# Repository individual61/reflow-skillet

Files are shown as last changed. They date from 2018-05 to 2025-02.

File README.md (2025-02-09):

# reflow-skillet

A reflow oven based on a cheap Target skillet, with OLED display screen and thermocouple input. Now on a custom PCB.

IMG_8690_result

IMG_4667_result

IMG_4640_result

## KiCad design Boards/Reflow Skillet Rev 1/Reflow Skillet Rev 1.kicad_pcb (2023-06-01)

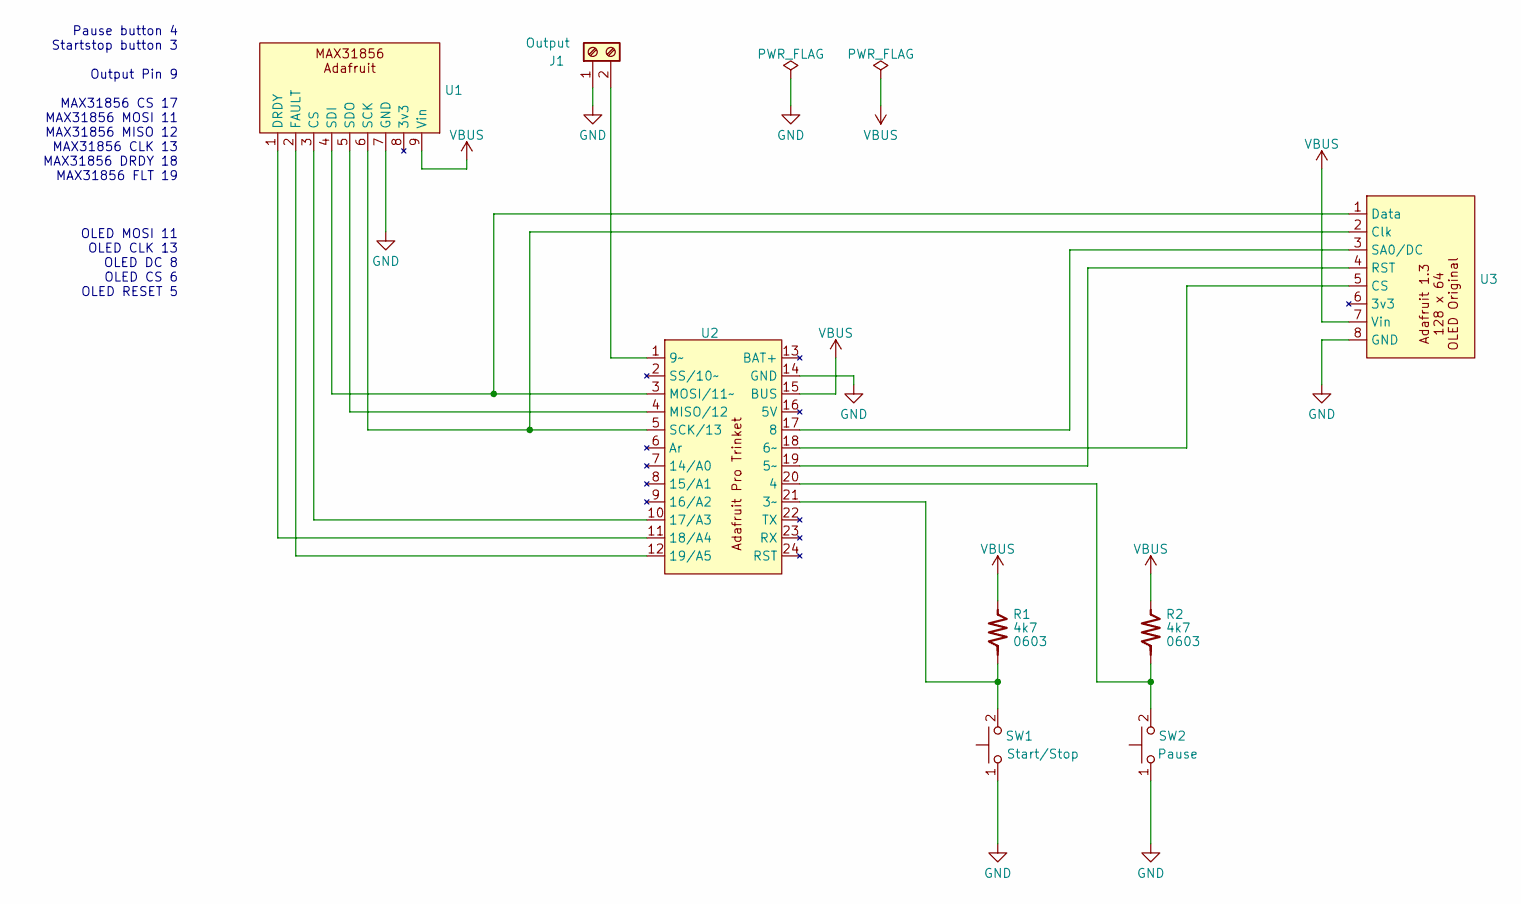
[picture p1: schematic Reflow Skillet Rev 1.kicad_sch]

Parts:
J1: Output; TerminalBlock_TE_282834-2_1x02_P2.54mm_Horizontal; MFR PN 282834-2; DIGIKEY PN A98333-ND
R1, R2: 4k7; R_0603_1608Metric_Pad0.98x0.95mm_HandSolder; MPN MFR P/N
SW1: Start/Stop; SW_TH_Tactile_Omron_B3F-10xx
SW2: Pause; SW_TH_Tactile_Omron_B3F-10xx
U1: Adafruit MAX31856
U2: Adafruit Pro Trinket
U3: Adafruit 1.3 128 x 64 OLED Original

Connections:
GND: J1.1, SW1.1, SW2.1, U1.7 (GND), U2.14 (GND), U3.8 (GND)
unnamed: J1.2, U2.1 (9~)
unnamed: U1.3 (CS), U2.10 (17/A3)
unnamed: U1.1 (DRDY), U2.11 (18/A4)
unnamed: U1.2 (FAULT), U2.12 (19/A5)
unnamed: U1.6 (SCK), U2.5 (SCK/13), U3.2 (Clk)
unnamed: U1.4 (SDI), U2.3 (MOSI/11~), U3.1 (Data)
unnamed: U1.5 (SDO), U2.4 (MISO/12)
unnamed: R1.2, SW1.2, U2.21 (3~)
unnamed: R2.2, SW2.2, U2.20 (4)
unnamed: U2.19 (5~), U3.4 (RST)
unnamed: U2.18 (6~), U3.5 (CS)
unnamed: U2.17 (8), U3.3 (SA0/DC)
VBUS: R1.1, R2.1, U1.9 (Vin), U2.15 (BUS), U3.7 (Vin)

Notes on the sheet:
Pause button 4 Startstop button 3 Output Pin 9 MAX31856 CS 17 MAX31856 MOSI 11 MAX31856 MISO 12 MAX31856 CLK 13 MAX31856 DRDY 18 MAX31856 FLT 19 OLED MOSI 11 OLED CLK 13 OLED DC 8 OLED CS 6 OLED RESET 5

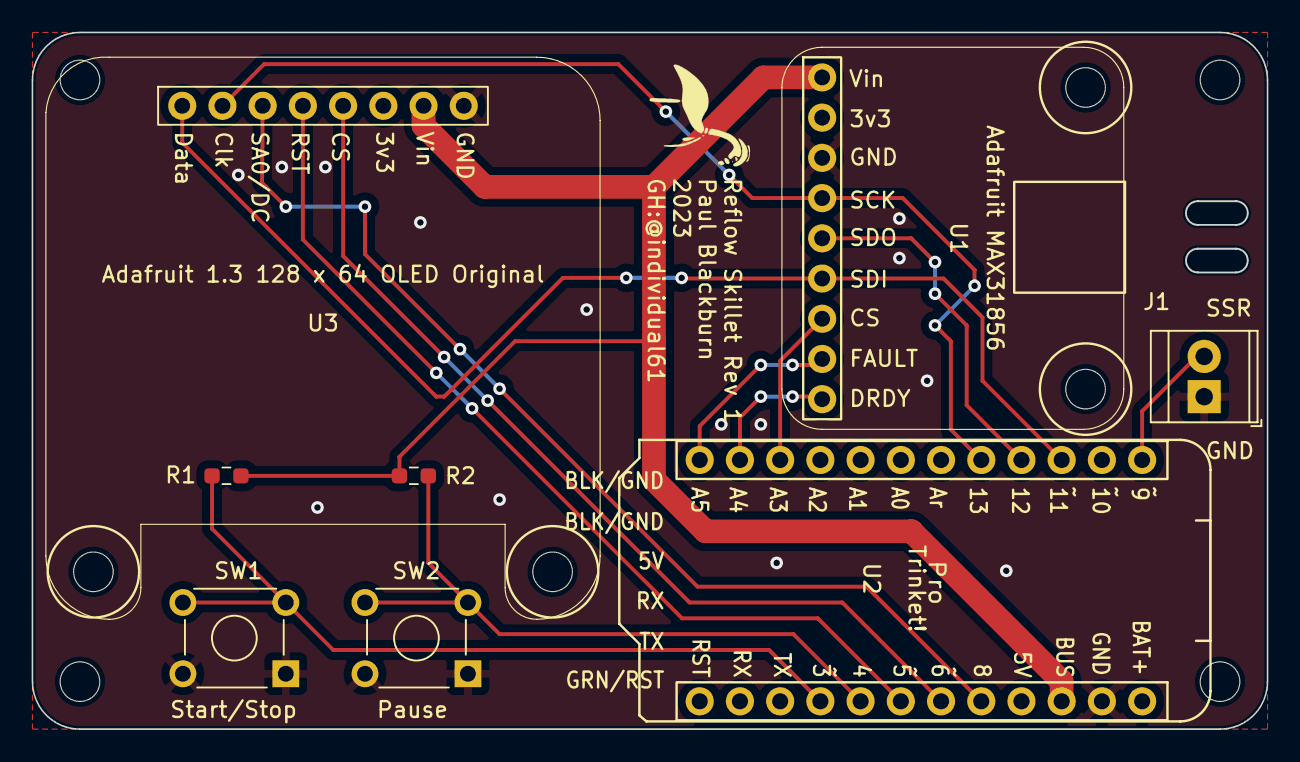
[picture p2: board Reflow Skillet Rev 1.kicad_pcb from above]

Board: 2 copper layers, 78.0 x 44.0 mm, 8 parts (0 on the bottom side), 14 nets.

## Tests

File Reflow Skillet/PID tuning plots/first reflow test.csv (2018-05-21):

Setpoint | Actual | Output
0 | 0 | 0
0 | 0 | 0
0 | 0 | 0
0 | 0 | 0
0 | 0 | 0
0 | 0 | 0
0 | 0 | 0
0 | 0 | 0
0 | 0 | 0
0 | 0 | 0
0 | 0 | 0
0 | 0 | 0
0 | 0 | 0
0 | 0 | 0
0 | 0 | 0
0 | 0 | 0
0 | 0 | 0
0 | 0 | 0
0 | 0 | 0
0 | 0 | 0
0 | 0 | 0
0 | 0 | 0
0 | 0 | 0
0 | 0 | 0
0 | 0 | 0
0 | 0 | 0
0 | 0 | 0
0 | 0 | 0
0 | 0 | 0
0 | 0 | 0
0 | 0 | 0
0 | 0 | 0
0 | 0 | 0
0 | 0 | 0
0 | 0 | 0
0 | 0 | 0
0 | 0 | 0
0 | 0 | 0
0 | 0 | 0
0 | 0 | 0
0 | 0 | 0
0 | 0 | 0
0 | 0 | 0
0 | 0 | 0
0 | 0 | 0
0 | 0 | 0
0 | 0 | 0
0 | 0 | 0
0 | 0 | 0
0 | 0 | 0
0 | 0 | 0
0 | 0 | 0
0 | 0 | 0
0 | 0 | 0
0 | 0 | 0
0 | 0 | 0
0 | 0 | 0
0 | 0 | 0
0 | 0 | 0
0 | 0 | 0
0 | 0 | 0
0 | 0 | 0
0 | 0 | 0
0 | 0 | 0
0 | 0 | 0
0 | 0 | 0
0 | 0 | 0
0 | 0 | 0
0 | 0 | 0
0 | 0 | 0
0 | 0 | 0
0 | 0 | 0
0 | 0 | 0
0 | 0 | 0
0 | 0 | 0
0 | 0 | 0
0 | 0 | 0
0 | 0 | 0
0 | 0 | 0
0 | 0 | 0
0 | 0 | 0
0 | 0 | 0
0 | 0 | 0
0 | 0 | 0
0 | 0 | 0
0 | 0 | 0
0 | 0 | 0
0 | 0 | 0
0 | 0 | 0
0 | 0 | 0
0 | 0 | 0
0 | 0 | 0
0 | 0 | 0
0 | 0 | 0
0 | 0 | 0
0 | 0 | 0
0 | 0 | 0
0 | 0 | 0
0 | 0 | 0
0 | 0 | 0
0 | 0 | 0
0 | 0 | 0
0 | 0 | 0
0 | 0 | 0
0 | 0 | 0
0 | 0 | 0
0 | 0 | 0
0 | 0 | 0
0 | 0 | 0
0 | 0 | 0
0 | 0 | 0
0 | 0 | 0
0 | 0 | 0
0 | 0 | 0
0 | 0 | 0
0 | 0 | 0
0 | 0 | 0
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

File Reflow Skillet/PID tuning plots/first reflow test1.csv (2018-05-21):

Setpoint | Actual | Output
0 | 0 | 0
0 | 0 | 0
0 | 0 | 0
0 | 0 | 0
0 | 0 | 0
0 | 0 | 0
0 | 0 | 0
0 | 0 | 0
0 | 0 | 0
0 | 0 | 0
0 | 0 | 0
0 | 0 | 0
0 | 0 | 0
0 | 0 | 0
0 | 0 | 0
0 | 0 | 0
0 | 0 | 0
0 | 0 | 0
0 | 0 | 0
0 | 0 | 0
0 | 0 | 0
0 | 0 | 0
0 | 0 | 0
0 | 0 | 0
0 | 0 | 0
0 | 0 | 0
0 | 0 | 0
0 | 0 | 0
0 | 0 | 0
0 | 0 | 0
0 | 0 | 0
0 | 0 | 0
0 | 0 | 0
0 | 0 | 0
0 | 0 | 0
0 | 0 | 0
0 | 0 | 0
0 | 0 | 0
0 | 0 | 0
0 | 0 | 0
0 | 0 | 0
0 | 0 | 0
0 | 0 | 0
0 | 0 | 0
0 | 0 | 0
0 | 0 | 0
0 | 0 | 0
0 | 0 | 0
0 | 0 | 0
0 | 0 | 0
0 | 0 | 0
0 | 0 | 0
0 | 0 | 0
0 | 0 | 0
0 | 0 | 0
0 | 0 | 0
0 | 0 | 0
0 | 0 | 0
0 | 0 | 0
0 | 0 | 0
0 | 0 | 0
0 | 0 | 0
0 | 0 | 0
0 | 0 | 0
0 | 0 | 0
0 | 0 | 0
0 | 0 | 0
0 | 0 | 0
0 | 0 | 0
0 | 0 | 0
0 | 0 | 0
0 | 0 | 0
0 | 0 | 0
0 | 0 | 0
0 | 0 | 0
0 | 0 | 0
0 | 0 | 0
0 | 0 | 0
0 | 0 | 0
0 | 0 | 0
0 | 0 | 0
0 | 0 | 0
0 | 0 | 0
0 | 0 | 0
0 | 0 | 0
0 | 0 | 0
0 | 0 | 0
0 | 0 | 0
0 | 0 | 0
0 | 0 | 0
0 | 0 | 0
0 | 0 | 0
0 | 0 | 0
0 | 0 | 0
0 | 0 | 0
0 | 0 | 0
0 | 0 | 0
0 | 0 | 0
0 | 0 | 0
0 | 0 | 0
0 | 0 | 0
0 | 0 | 0
0 | 0 | 0
0 | 0 | 0
0 | 0 | 0
0 | 0 | 0
0 | 0 | 0
0 | 0 | 0
0 | 0 | 0
0 | 0 | 0
0 | 0 | 0
0 | 0 | 0
0 | 0 | 0
0 | 0 | 0
0 | 0 | 0
0 | 0 | 0
0 | 0 | 0
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

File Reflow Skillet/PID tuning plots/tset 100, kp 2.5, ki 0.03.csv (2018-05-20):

Setpoint | Actual | Output
0 | 0 | 0
0 | 0 | 0
0 | 0 | 0
0 | 0 | 0
0 | 0 | 0
0 | 0 | 0
0 | 0 | 0
0 | 0 | 0
0 | 0 | 0
0 | 0 | 0
0 | 0 | 0
0 | 0 | 0
0 | 0 | 0
0 | 0 | 0
0 | 0 | 0
0 | 0 | 0
0 | 0 | 0
0 | 0 | 0
0 | 0 | 0
0 | 0 | 0
0 | 0 | 0
0 | 0 | 0
0 | 0 | 0
0 | 0 | 0
0 | 0 | 0
0 | 0 | 0
0 | 0 | 0
0 | 0 | 0
0 | 0 | 0
0 | 0 | 0
0 | 0 | 0
0 | 0 | 0
0 | 0 | 0
0 | 0 | 0
0 | 0 | 0
0 | 0 | 0
0 | 0 | 0
0 | 0 | 0
0 | 0 | 0
0 | 0 | 0
0 | 0 | 0
0 | 0 | 0
0 | 0 | 0
0 | 0 | 0
0 | 0 | 0
0 | 0 | 0
0 | 0 | 0
0 | 0 | 0
0 | 0 | 0
0 | 0 | 0
0 | 0 | 0
0 | 0 | 0
0 | 0 | 0
0 | 0 | 0
0 | 0 | 0
0 | 0 | 0
0 | 0 | 0
0 | 0 | 0
0 | 0 | 0
0 | 0 | 0
0 | 0 | 0
0 | 0 | 0
0 | 0 | 0
0 | 0 | 0
0 | 0 | 0
0 | 0 | 0
0 | 0 | 0
0 | 0 | 0
0 | 0 | 0
0 | 0 | 0
0 | 0 | 0
0 | 0 | 0
0 | 0 | 0
0 | 0 | 0
0 | 0 | 0
0 | 0 | 0
0 | 0 | 0
0 | 0 | 0
0 | 0 | 0
0 | 0 | 0
0 | 0 | 0
0 | 0 | 0
0 | 0 | 0
0 | 0 | 0
0 | 0 | 0
0 | 0 | 0
0 | 0 | 0
0 | 0 | 0
0 | 0 | 0
0 | 0 | 0
0 | 0 | 0
0 | 0 | 0
0 | 0 | 0
0 | 0 | 0
0 | 0 | 0
0 | 0 | 0
0 | 0 | 0
0 | 0 | 0
0 | 0 | 0
0 | 0 | 0
0 | 0 | 0
0 | 0 | 0
0 | 0 | 0
0 | 0 | 0
0 | 0 | 0
0 | 0 | 0
0 | 0 | 0
0 | 0 | 0
0 | 0 | 0
0 | 0 | 0
0 | 0 | 0
0 | 0 | 0
0 | 0 | 0
0 | 0 | 0
0 | 0 | 0
0 | 0 | 0
0 | 0 | 0
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

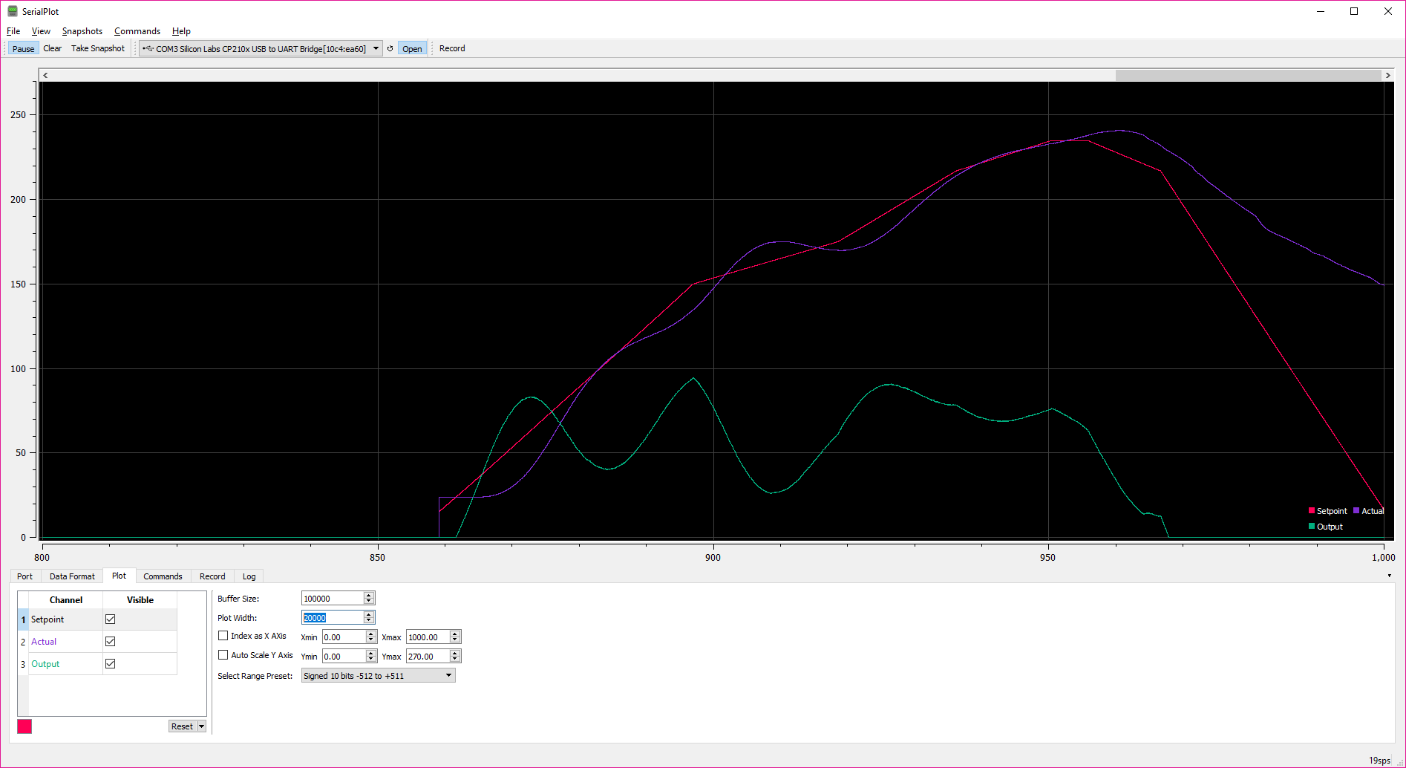
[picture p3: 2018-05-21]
Reflow Skillet/PID tuning plots/POV Stick 5050 #1.PNG

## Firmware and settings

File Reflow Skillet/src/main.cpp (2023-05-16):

#include "parameters.h"

// Modified Adafruit thermocouple library per
// https://forums.adafruit.com/viewtopic.php?f=19&t=108896

// If the screen looks stretched vertically, and skips lines, then the Adafruit
// library header file must be edited as parameters
// https://learn.adafruit.com/monochrome-oled-breakouts/arduino-library-and-examples

// Plot with
// https://hackaday.io/project/5334-serialplot-realtime-plotting-software

//////////////////////// GLOBALS

// Display globals

// This is for software SPI
// Adafruit_SSD1306 display(SCREEN_WIDTH, SCREEN_HEIGHT, OLED_MOSI, OLED_CLK, OLED_DC, OLED_RESET, OLED_CS);

// We want hardware SPI
Adafruit_SSD1306 display(SCREEN_WIDTH, SCREEN_HEIGHT, &SPI, OLED_DC, OLED_RESET, OLED_CS);

// Thermocouple globals

// This is software SPI
// Adafruit_MAX31856 max = Adafruit_MAX31856(MAX31856_CS, MAX31856_MOSI, MAX31856_MISO, MAX31856_CLK);

// We want hardware SPI (to use hardware SPI, just pass in the CS pin)
Adafruit_MAX31856 max = Adafruit_MAX31856(MAX31856_CS);

float g_coldtemp = 0.0;
float g_thtemp = 0.0;
float g_tset = 0.0;
uint8_t g_fault = 0;
uint32_t g_previous_temp_read_time = 0;

// Button globalS
//

// Profile globals
uint8_t g_currentStep = 0;
uint32_t g_timeStepStart = 0;
uint32_t g_timeStepElapsed = 0;
uint32_t g_step_duration = 0;
double g_t_ramp_start = 0.0;
double g_t_ramp_end = 0.0;

double profile_times[] =
	{
		210, // 0, to 120
		120, // 1, to 160
		100, // 2, to 210
		80,	 // 3, to 210
		30,	 // 4, to 170
		60,	 // 5, to 100
		180	 // 6 to 15
};

double profile_temps[] =
	{
		120.0, // 0
		160.0, // 1
		210.0, // 2
		210.0, // 3  // paste says 249, but APA102C says 235
		170.0, // 4
		100.0, // 5
		15.0};

/* As found from 2018. Probably good for APA102C. 
double profile_times[] =
	{
		210, // 0, to 150
		120, // 1, to 175
		100, // 2, to 217
		80,	 // 3, to 235
		30,	 // 4, to 235
		60,	 // 5, to 217
		180	 // 6 to 15
};

double profile_temps[] =
	{
		150.0, // 0
		175.0, // 1
		217.0, // 2
		235.0, // 3  // paste says 249, but APA102C says 235
		235.0, // 4
		217.0, // 5
		15.0};
*/


/*
   double profile_times[] =
   {
		1.0, // 0
		2000.0, // 1
		3.0, // 2
		4.0, // 3
		5.0 // 4
   };

   double profile_temps[] =
   {
		100, // 0
		100, // 1
		100, // 2
		100, // 3
		15 // 4
   };
 */

// State Machine globals
State_enum theState = idle;
bool g_heartbeat = 0;

// PID globalS
bool g_heating = 0;

float g_fake_temp = 25.0;

uint32_t g_windowStartTime = 0;

double g_PID_setpoint = 0; // from profile
double g_PID_output = 0;   // control relay ON time
double g_PID_input = 0;	   // measured temp

PID myPID(&g_PID_input, &g_PID_output, &g_PID_setpoint, KP, KI, KD, DIRECT);

///////////////////////////// END GLOBALS

void setup()
{

	Serial.begin(115200);

	theState = idle;
	g_fault = 0;

	// Thermocouple stuff
	if (!max.begin())
	{
		Serial.println("# Could not initialize thermocouple.");
	}
	Serial.println("# MAX31856 initialized successfully.");

	max.setThermocoupleType(MAX31856_TCTYPE_K);
	max.setConversionMode(MAX31856_CONTINUOUS);
	//max.config();
	update_temps();

	// Profile stuff
	g_currentStep = 0;

	// OLED stuff
	// display.begin(SSD1306_SWITCHCAPVCC);
	// SSD1306_SWITCHCAPVCC = generate display voltage from 3.3V internally
	if (!display.begin(SSD1306_SWITCHCAPVCC))
	{
		Serial.println(F("SSD1306 allocation failed"));
		for (;;)
			; // Don't proceed, loop forever
	}

	display.clearDisplay();
	display.display();
	display.setTextSize(1);
	display.setTextColor(WHITE);
	display.setCursor(0, 0);
	display.clearDisplay();
	display.display();
	// PID stuff
	g_heating = 0;
	g_windowStartTime = millis();
	myPID.SetOutputLimits(0, PID_OUTPUTLIMIT);
	myPID.SetMode(AUTOMATIC);
	myPID.SetSampleTime(PID_SAMPLE_TIME);

	// SSR stuff
	pinMode(OUTPUT_PIN, OUTPUT);
	digitalWrite(OUTPUT_PIN, LOW);
}

void loop()
{
	g_heartbeat = !g_heartbeat;

	switch (theState)
	{

	case idle: ///////////////////////////// IDLE
		checkPauseButton();
		checkStartStopButton();
		update_temps();
		delay(10);
		update_display();
		g_heating = 0;
		digitalWrite(OUTPUT_PIN, LOW);
		break;

	case running: ///////////////////////////// RUNNING
		checkPauseButton();
		checkStartStopButton();
		update_temps();
		g_timeStepElapsed = millis() - g_timeStepStart;

		calculate_tset_from_ramp(g_t_ramp_start, g_t_ramp_end, profile_times[g_currentStep], (double)(g_timeStepElapsed / 1000.0)); // also sets g_PID_setpoint
		update_PID_and_set_output();
		update_display();

		//	Serial.print(F("g_t_ramp_start "));
		//	Serial.print(g_t_ramp_start);
		//		Serial.print(F("\tg_t_ramp_end "));
		//		Serial.print(g_t_ramp_end);
		//		Serial.print(F("\tprofile_times[g_currentStep] "));
		//		Serial.print(profile_times[g_currentStep]);
		//		Serial.print(F("\tg_timeStepElapsed/1000.0 "));
		//		Serial.print(g_timeStepElapsed/1000.0);
		//		Serial.print(F("\tg_tset "));
		//		Serial.print(F("\t"));
		Serial.print(g_tset);
		//	Serial.print(F("\t g_thtemp"));
		Serial.print(F("\t"));
		Serial.print(g_thtemp);
		Serial.print(F("\t"));
		Serial.println(g_PID_output);

		if (g_timeStepElapsed > (1000 * profile_times[g_currentStep]))
		{
			advance_to_next_step();
		}
		break;

	case fault: ///////////////////////////// FAULT
		digitalWrite(OUTPUT_PIN, LOW);
		g_heating = 0;
		display.clearDisplay();
		display.setCursor(0, 0);
		display.println(F("Fault: "));

		display_fault();

		g_fault = max.readFault();
		Serial.println(F("# In Fault state. Fault is reported as: "));
		Serial.println(g_fault);
		if (!g_fault)
		{
			theState = idle;
		}
		break;

	case pause: ///////////////////////////// PAUSED
		checkPauseButton();
		checkStartStopButton();
		update_temps();
		update_PID_and_set_output();
		update_display();

		break;
	}

	delay(10);
}

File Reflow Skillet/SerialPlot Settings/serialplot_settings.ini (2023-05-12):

[MainWindow]
size=@Size(959 911)
pos=@Point(2351 403)
activePanel=Plot
hidePanels=false
maximized=false
state=@ByteArray(\0\0\0\xff\0\0\0\0\xfd\0\0\0\0\0\0\x3\xbf\0\0\x3\x44\0\0\0\x4\0\0\0\x4\0\0\0\b\0\0\0\b\xfc\0\0\0\x1\0\0\0\x2\0\0\0\x3\0\0\0\f\0t\0\x62\0P\0l\0o\0t\x1\0\0\0\0\xff\xff\xff\xff\0\0\0\0\0\0\0\0\0\0\0\x1a\0t\0\x62\0P\0o\0r\0t\0\x43\0o\0n\0t\0r\0o\0l\x1\0\0\0i\xff\xff\xff\xff\0\0\0\0\0\0\0\0\0\0\0\x10\0t\0\x62\0R\0\x65\0\x63\0o\0r\0\x64\x1\0\0\x1\xf9\xff\xff\xff\xff\0\0\0\0\0\0\0\0)

[Port]
selectedPort=
baudRate=115200
parity=none
dataBits=8
stopBits=1
flowControl=none

[DataFormat]
format=ascii

[DataFormat_Binary]
numOfChannels=2
numberFormat=uint8
endianness=little

[DataFormat_ASCII]
numOfChannels=3
delimiter=TAB
customDelimiter=|
filterMode=exclude
filterPrefix=#

[DataFormat_CustomFrame]
numOfChannels=1
numberFormat=uint8
endianness=little
frameStart=AA BB
fixedSize=false
frameSize=1
checksum=false
debugMode=false

[Channels]
channel\1\name=T_set
channel\1\color=@Variant(\0\0\0\x43\x1\xff\xff\xff\xff\0\0VV\0\0)
channel\1\visible=true
channel\1\gain=1
channel\1\gainEnabled=false
channel\1\offset=0
channel\1\offsetEnabled=false
channel\2\name=T_act
channel\2\color=@Variant(\0\0\0\x43\x1\xff\xff~~--\xd2\xd2\0\0)
channel\2\visible=true
channel\2\gain=1
channel\2\gainEnabled=false
channel\2\offset=0
channel\2\offsetEnabled=false
channel\3\name=Output%
channel\3\color=@Variant(\0\0\0\x43\x1\xff\xff\0\0\xae\xae~~\0\0)
channel\3\visible=true
channel\3\gain=1
channel\3\gainEnabled=false
channel\3\offset=0
channel\3\offsetEnabled=false
channel\size=3

[Plot]
numOfSamples=100000
plotWidth=100000
indexAsX=true
xMax=1000
xMin=0
autoScale=true
yMax=1000
yMin=0
darkBackground=false
grid=false
minorGrid=false
legend=true
multiPlot=false
symbols=auto
numLines=1000
decimals=6

[Commands]
command\1\name=Command 1
command\1\type=ascii
command\1\data=
command\size=1

[Record]
autoIncrement=true
recordPaused=true
stopOnClose=true
header=true
disableBuffering=false
separator=","
decimals=6
timestamp=true
timestampFormat=seconds_with_precision

[UpdateCheck]
periodicCheck=true
lastCheck=2023-05-09

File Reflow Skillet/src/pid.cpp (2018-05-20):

#include "parameters.h"

void update_PID_and_set_output(void)
{
//  g_PID_input = g_fake_temp;
	g_PID_input = g_thtemp;
	g_PID_setpoint = g_tset;

	myPID.Compute();
//  Serial.print(F("g_PID_input: "));
//  Serial.print(g_PID_input);
//  Serial.print(F(",\t"));
//  Serial.print(F("g_PID_output: "));
//  Serial.print(g_PID_output);
//  Serial.print(F(",\t"));
//  Serial.print(F("g_PID_setpoint: "));
//  Serial.print(g_PID_setpoint);

	uint32_t time_elapsed_in_window;
	time_elapsed_in_window = (millis() - g_windowStartTime);
// millis() - g_windowStartTime is the time elapsed in this window
	if (time_elapsed_in_window >
	    WINDOWSIZE) { // shift window forward by WINDOWSIZE if we have moved
		          // beyond WINDOWSIZE ms from g_windowStartTime
		g_windowStartTime = g_windowStartTime + WINDOWSIZE;
	}
	if (g_PID_output * WINDOWSIZEDIV100 < time_elapsed_in_window) // off time
	{
		g_heating = 0;
		digitalWrite(OUTPUT_PIN, LOW);
//
	} else // on time
	{
		g_heating = 1;
		//  Serial.println(F("\tHEATING"));
		digitalWrite(OUTPUT_PIN, HIGH);
	}

	return;
};

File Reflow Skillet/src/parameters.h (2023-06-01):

#ifndef PARAMETERS_H
#define PARAMETERS_H

//#include "Adafruit_MAX31856_modified.h"
#include <Adafruit_MAX31856.h>
#include "buttons.h"
#include "display.h"
#include "pid.h"
#include "profile.h"
#include "temp.h"
#include <Adafruit_GFX.h>
#include <Adafruit_SSD1306.h>
#include <Arduino.h>
#include "PID_V1_modified.h"
#include <avr/pgmspace.h>

///////////////////
// SSR/LED output
#define OUTPUT_PIN 9
#define LED_PIN 0
///////////////////
// Buttons

#define PAUSE_BTN 4
#define STARTSTOP_BTN 3
#define DEBOUNCEDELAY 2000

/////////////////// SPI
// Pro Trinket SPI Connections (common to both devices)

// MOSI/SDI 11
// MISO/SDO 12
// SCK 13

/////////////////// Thermocouple
// Use software SPI: CS, DI, DO, CLK
#define MAX31856_CS 17 // 18 //10
#define MAX31856_MOSI 11
#define MAX31856_MISO 12
#define MAX31856_CLK 13
#define MAX31856_DRDY 18
#define MAX31856_FLT 19


#define TEMP_POLL_INTERVAL_MS 150

/////

/////////////////// OLED
// If using software SPI (the default case):
#define OLED_MOSI 11
#define OLED_CLK 13
#define OLED_DC 8
#define OLED_CS 6
#define OLED_RESET 5

// Start OLED preamble
//#define LOGO16_GLCD_HEIGHT 16
//#define LOGO16_GLCD_WIDTH 16

#define SCREEN_WIDTH 128 // OLED display width, in pixels
#define SCREEN_HEIGHT 64 // OLED display height, in pixels

//#if (SSD1306_LCDHEIGHT != 64)
//#error("Height incorrect, please fix Adafruit_SSD1306.h!");
//#endif
// end OLED preamble

/////////////////// PID
#define PID_OUTPUTLIMIT 100.0
#define KP (100.0 / 40.0)   // denominator is temp in deg C that will elicit 100% output
#define KI 0.03
#define KD 0.0
#define WINDOWSIZE 3000     // minimum SSR cycle period in ms
#define WINDOWSIZEDIV100 30 // window size divided by 100
#define PID_SAMPLE_TIME 200 // how often PID loop is updated



/////////////////// Profile
#define INITIAL_PROFILE_TEMP 15
//////////////////////// GLOBALS
// Display globals
extern Adafruit_SSD1306 display;

// Thermocouple globals
extern Adafruit_MAX31856 max;
// use hardware SPI, just pass in the CS pin
// Adafruit_MAX31856 max = Adafruit_MAX31856(10);
extern float g_coldtemp;
extern float g_thtemp;
extern float g_tset;
extern uint8_t g_fault;
extern uint32_t g_previous_temp_read_time;

// Button globalS

// State machine globalS

enum State_enum { running, idle, fault, pause };
extern State_enum theState;

extern bool g_heartbeat;

// Profile globals
extern uint8_t g_currentStep;
extern uint32_t g_timeStepStart;
extern uint32_t g_timeStepElapsed;
extern uint32_t g_step_duration;
extern double g_t_ramp_start;
extern double g_t_ramp_end;

#define NUMBER_OF_PROFILE_STEPS 7
extern double profile_times[NUMBER_OF_PROFILE_STEPS];
extern double profile_temps[NUMBER_OF_PROFILE_STEPS];


// PID globalS
extern PID myPID;
extern bool g_heating;

extern float g_fake_temp;
extern uint32_t g_windowStartTime;

extern double g_PID_setpoint; // from profile
extern double g_PID_output;   // control relay ON time
extern double g_PID_input;    // measured temp

#endif

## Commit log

2018-04-20 Adafruit Example is working
    Implemented Adafruit's example. Reads back CJ temp and Th temp. Reports faults. Serial. Uses software SPI pins.
2018-05-02 Added OLED test code
    OLED is wired up and runs the Adafruit test code!
2018-05-04 Basic screen support, fault detection
    Implemented state machine with idle, running, fault.
    Faults are apparently reset by power cycling device. Not sure if this is an issue with my program or not.
    [main.cpp]
2018-05-04 Created temp, display and button files
    Split code across temp, display, and button C++/header files.
    Added parameters.h as common header.
2018-05-05 Sketched button actions
    Buttons are Start/Stop and Pause/Unpause. Added placeholders for transition functions.
2018-05-06 Fixing mangled files
    Somehow (Atom? Platformio?) an awful chimera of main.cpp and parameters.h was created, and I have no idea why.
    First attempt at fixing. Only compile error is the Config() member of the thermocouple Adafruit library. Had to make a modification to avoid the 250 ms delay per read (!).
    [buttons.cpp, display.cpp, main.cpp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]
2018-05-07 Finished reworking temp query delay
    Querying temperature is now < 1 ms and is done every N ms.
    Added dot in lower right to indicate each run through loop().
    Fixed display size issue by editing the library header again (for some reason this works, when for the temperature library it seems that the header file I edited was not being used).
    Fixed running/paused/idle transitions.
    [buttons.cpp, display.cpp, main.cpp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]
2018-05-07 Fixed most of the overwriting problem
    [main.cpp, parameters.h]
2018-05-08 Added heating indicator
    And made it purty.
2018-05-09 Adding PID
    Adding PID. Incomplete. Testing.
2018-05-15 Adding source files for PID library
    Wasn't successful editing PlatformIO libraries at the origin, and the PID library doesn't seem to have a straightforward reset function.
2018-05-17 Fixed a few things
    Output not turning off after going to Idle,
    Time remaining was counting (number of steps) times (first step time)
    etc
    [buttons.cpp, display.cpp, main.cpp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]
2018-05-20 Tuning PID
    Definitely not there yet
2018-05-20 First good PID test
    Setpoint 100 deg C, was stable. Lid on.
    [tset 100, kp 2.5, ki 0.03.csv]
2018-05-20 First reflow test
    On a perf board
2018-05-21 Removed serial output for plotting
    Version as used to reflow POV Stick 5050 Rev A #1
    [POV Stick 5050 #1.csv, first reflow test.csv]
2020-09-20 Tidying up
    [first reflow test1.csv]
2023-05-12 Right before changes to address screen glitch.
    [Output.csv]
2023-05-16 Finally fixed, modified profile for low temp solder
    [display.cpp, main.cpp, parameters.h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]
2023-05-31 Making a carrier board
    [Adafruit 1.3in 128x64 OLED STEMMA QT.brd, Adafruit 1.3in 128x64 OLED STEMMA QT.sch, Adafruit Pro Trinket 3v3.brd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]
2023-06-01 Board before routing
    [Adafruit MAX31856.brd, Adafruit MAX31856.kicad_pcb, Adafruit MAX31856.sch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]
2023-06-01 As sent to jlcpcb
    [Adafruit 1.3in 128x64 OLED STEMMA QT.brd, Adafruit 1.3in 128x64 OLED STEMMA QT.sch, Adafruit MAX31856.brd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]
